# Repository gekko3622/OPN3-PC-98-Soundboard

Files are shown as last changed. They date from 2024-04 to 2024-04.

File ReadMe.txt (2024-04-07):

  ___  ____  _   _ _____  __     ______    ___  
 / _ \|  _ \| \ | |___ /  \ \   / /___ \  / _ \ 
| | | | |_) |  \| | |_ \   \ \ / /  __) || | | |
| |_| |  __/| |\  |___) |   \ V /  / __/ | |_| |
 \___/|_|   |_| \_|____/     \_/  |_____(_)___/ 

PC-9801/9821 Soundboard
2024.3 by RLB (Gekko3622)
Original schematic by Ethy1ene

Intro:

This ZIP archive contains all files related to my implementation of Ethy1ene's publicly released OPN3 schematic. Please feel free to modify or improve it in any way you see fit.

------------------------------------------------------------------------------------------------------

ZIP Contents:

1. KiCAD Project - Contains the full KiCad project for my version of the OPN3 soundboard.

2. Production Files - Contains all files necessary to produce the exact PCB that I have. 
   
   I HIGHLY RECOMMEND paying your PCB fabricator to supply and assemble the small SMD devices. 
   This folder includes turnkey BOM and top placement files formatted for JLCPCB.
   
   This will include my logo on the PCB, as it is guaranteed to be an exact match to my own design.
   If you wish to produce a PCB without my logo, you will need to export new fabrication files from KiCad.

3. JEDEC File - Contains a .JED file that must be programmed to the GAL20V8.
                This is mandatory. Please ensure you have a programmer that can write to a GAL20V8.

4. DigiKey Order List - Lists all components I purchased from DigiKey. Anything not on this list was 
   purchased for assembly by JLCPCB or needed to be purchased used or new old stock (see below).

------------------------------------------------------------------------------------------------------

Used/New Old Stock Parts Required:

1. YMF288-M Sound Chip
2. NEC UPD6379GR 16-Bit DAC
3. Lattice GAL20V8B-25LP Programmable Logic Device (PLD)

Note 1: UPD6379A is a pin-reversed variant. If you use it for some reason, it needs to be rotated 180 degrees.
Note 2: National Semiconductor makes a GAL20V8 which is still available. I have not tested it and cannot tell you which part number would be the best match.

------------------------------------------------------------------------------------------------------

Credits:

HUGE thanks to Ethy1ene for releasing his original OPN3 soundboard schematic and providing advice and troubleshooting. Without his help, this project wouldn't exist.

Thanks also to TD-Linux and i509VCB for their advice and guidance, pushing me to learn better practices as I worked.

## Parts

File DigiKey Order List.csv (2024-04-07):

Index | DigiKey Part # | Manufacturer Part Number | Description | Customer Reference | Quantity | Backorder | Unit Price | Extended Price
1 | FK0800019QDICT-ND | FK0800019Q | XTAL OSC XO 8.0000MHZ CMOS SMD | X1 | 1 | 0 | $1.31 | $1.31
2 | 296-3677-1-ND | SN74LS245NSR | IC TXRX NON-INVERT 5.25V 20SO | U4 | 1 | 0 | $1.20 | $1.20
3 | AZ1117IH-5.0TRG1DICT-ND | AZ1117IH-5.0TRG1 | IC REG LINEAR 5V 1A SOT223 | U8 | 1 | 0 | $0.38 | $0.38
4 | LM386MX-1/NOPBCT-ND | LM386MX-1/NOPB | IC AMP CLASS AB MONO 325MW 8SOIC | U7 | 1 | 0 | $1.11 | $1.11
5 | 296-LM2904DRCT-ND | LM2904DR | IC OPAMP GP 2 CIRCUIT 8SOIC | U6 | 1 | 0 | $0.41 | $0.41
6 | 1727-2787-1-ND | 74HC164D,653 | IC SHIFT REGST 8BIT SI-PO 14SOIC | U5 | 1 | 0 | $0.46 | $0.46
7 | CP1-3535NS-ND | SJ1-3535NS | CONN JACK STEREO 3.5MM R/A |  | 1 | 0 | $1.49 | $1.49
8 | 4809-RK09K1110A0J-ND | RK09K1110A0J | POT 10K OHM 1/20W LINEAR | RV1 | 1 | 0 | $1.80 | $1.80
 |  |  |  |  |  |  | Subtotal | $8.16

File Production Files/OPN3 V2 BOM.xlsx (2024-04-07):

Comment | Designator | Footprint | Quantity | JLCPCB Part #（optional）
10UF | C1 | Capacitor_Tantalum_SMD:CP_EIA-3216-18_Kemet-A | 1 | Basic C7171
10UF | C2, C4, C8 | Capacitor_SMD:C_0603_1608Metric | 3 | Basic C96446
0.1UF | C3, C16, C17, C18, C19, C20, C21, C22, C23 | Capacitor_SMD:C_0603_1608Metric | 9 | Basic C14663
2.2UF | C5, C9 | Capacitor_SMD:C_0603_1608Metric | 2 | Basic C23630
200PF | C6, C10 | Capacitor_SMD:C_0603_1608Metric | 2 | Extended C113796
10UH | L1, L2 | Inductor_SMD:L_1206_3216Metric | 2 | Extended C1051
1K | R1, R2, R3 | Resistor_SMD:R_0603_1608Metric | 3 | Basic C21190
10K | R4, R9, R11, R12, R17, R18, R19, R20, R21 | Resistor_SMD:R_0603_1608Metric | 9 | Basic C25804
470 | R5 | Resistor_SMD:R_0603_1608Metric | 1 | Basic C23179
680 | R6 | Resistor_SMD:R_0603_1608Metric | 1 | Basic C23228
3.3K | R7, R13 | Resistor_SMD:R_0603_1608Metric | 2 | Basic C22978
10 | R8, R14 | Resistor_SMD:R_0603_1608Metric | 2 | Basic C22859
5.6K | R10, R15 | Resistor_SMD:R_0603_1608Metric | 2 | Basic C23189
1.2K | R16 | Resistor_SMD:R_0603_1608Metric | 1 | Basic C22765

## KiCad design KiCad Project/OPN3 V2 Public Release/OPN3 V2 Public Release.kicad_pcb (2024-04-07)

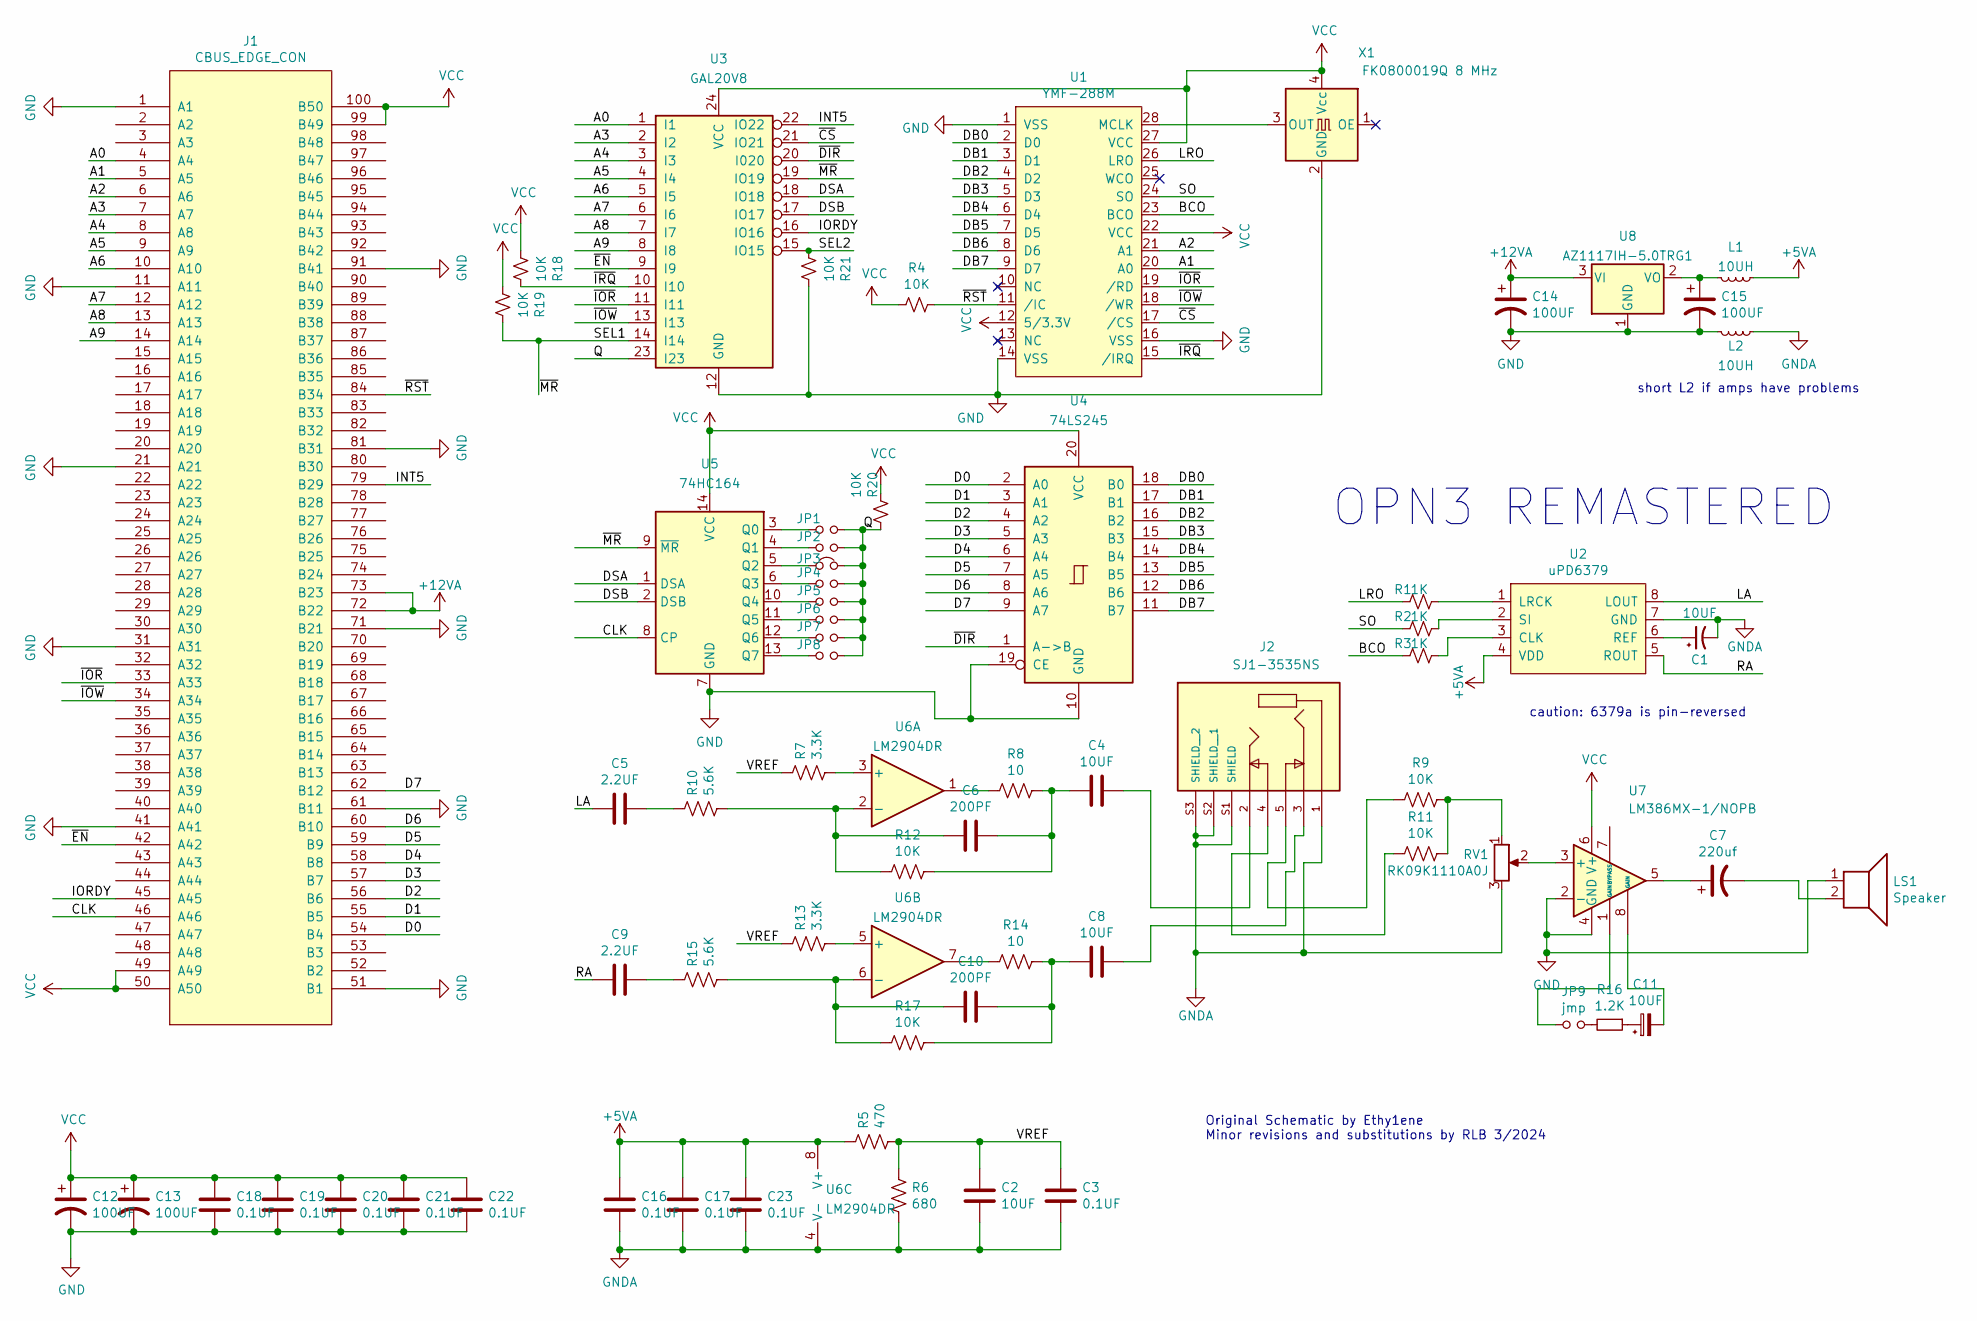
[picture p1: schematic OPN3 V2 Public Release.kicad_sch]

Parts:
C1: 10UF; CP_EIA-3216-18_Kemet-A
C2, C4, C8: 10UF; C_0603_1608Metric
C3, C16, C17, C18, C19, C20, C21, C22, C23: 0.1UF; C_0603_1608Metric
C5, C9: 2.2UF; C_0603_1608Metric
C6, C10: 200PF; C_0603_1608Metric
C7: 220uf; CP_Radial_D5.0mm_P2.50mm
C11: 10UF; CP_Radial_D6.3mm_P2.50mm
C12, C13, C14, C15: 100UF; CP_Radial_D6.3mm_P2.50mm
J1: CBUS_EDGE_CON; PC-98 CBus Pads 1-100
J2: SJ1-3535NS; CUI_SJ1-3535NS
JP1, JP2, JP4, JP5, JP6, JP7, JP8: Jumper_NO_Small; SolderJumper-2_P1.3mm_Open_Pad1.0x1.5mm
JP3: W; SolderJumper-2_P1.3mm_Bridged_Pad1.0x1.5mm
JP9: jmp; SolderJumper-2_P1.3mm_Open_Pad1.0x1.5mm
L1, L2: 10UH; L_1206_3216Metric
LS1: Speaker; PinHeader_1x02_P2.54mm_Vertical
R1, R2, R3: 1K; R_0603_1608Metric
R4, R9, R11, R12, R17, R18, R19, R20, R21: 10K; R_0603_1608Metric
R5: 470; R_0603_1608Metric
R6: 680; R_0603_1608Metric
R7, R13: 3.3K; R_0603_1608Metric
R8, R14: 10; R_0603_1608Metric
R10, R15: 5.6K; R_0603_1608Metric
R16: 1.2K; R_0603_1608Metric
RV1: RK09K1110A0J; Potentiometer_Alps_RK09K_Single_Horizontal; Part# ALPS RK09K1110B1R
U1: YMF-288M; YMF288-M; DigiKey Link None, source used/new old stock
U2: uPD6379; SOIC-8_5.23x5.23mm_P1.27mm; DigiKey Link None, source used/new old stock
U3: GAL20V8; DIP-24_W7.62mm
U4: 74LS245; SO-20_5.3x12.6mm_P1.27mm
U5: 74HC164; SO-14_5.3x10.2mm_P1.27mm
U6: LM2904DR; SOIC-8_5.23x5.23mm_P1.27mm
U7: LM386MX-1/NOPB; SOIC-8_5.23x5.23mm_P1.27mm
U8: AZ1117IH-5.0TRG1; SOT-223-3_TabPin2
X1: FK0800019Q 8 MHz; Oscillator_SMD_SeikoEpson_SG8002CE-4Pin_3.2x2.5mm_HandSolde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

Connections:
+5VA: C16.1, C17.1, C23.1, L1.2, R5.1, U2.4 (VDD), U6.8 (V+)
+12VA: C14.1, J1.72 (B22), J1.73 (B23), U8.3 (VI)
/A0: J1.4 (A4), U3.1 (I1)
/A1: J1.5 (A5), U1.20 (A0)
/A2: J1.6 (A6), U1.21 (A1)
/A3: J1.7 (A7), U3.2 (I2)
/A4: J1.8 (A8), U3.3 (I3)
/A5: J1.9 (A9), U3.4 (I4)
/A6: J1.10 (A10), U3.5 (I5)
/A7: J1.12 (A12), U3.6 (I6)
/A8: J1.13 (A13), U3.7 (I7)
/A9: J1.14 (A14), U3.8 (I8)
/BCO: R3.1, U1.23 (BCO)
/CLK: J1.46 (A46), U5.8 (CP)
/D0: J1.54 (B4), U4.2 (A0)
/D1: J1.55 (B5), U4.3 (A1)
/D2: J1.56 (B6), U4.4 (A2)
/D3: J1.57 (B7), U4.5 (A3)
/D4: J1.58 (B8), U4.6 (A4)
/D5: J1.59 (B9), U4.7 (A5)
/D6: J1.60 (B10), U4.8 (A6)
/D7: J1.62 (B12), U4.9 (A7)
/DB0: U1.2 (D0), U4.18 (B0)
/DB1: U1.3 (D1), U4.17 (B1)
/DB2: U1.4 (D2), U4.16 (B2)
/DB3: U1.5 (D3), U4.15 (B3)
/DB4: U1.6 (D4), U4.14 (B4)
/DB5: U1.7 (D5), U4.13 (B5)
/DB6: U1.8 (D6), U4.12 (B6)
/DB7: U1.9 (D7), U4.11 (B7)
/DSA: U3.18 (IO18), U5.1 (DSA)
/DSB: U3.17 (IO17), U5.2 (DSB)
/INT5: J1.79 (B29), U3.22 (IO22)
/IORDY: J1.45 (A45), U3.16 (IO16)
/LA: C5.1, U2.8 (LOUT)
/LRO: R1.1, U1.26 (LRO)
/Q: JP1.2, JP2.2, JP3.2, JP4.2, JP5.2, JP6.2, JP7.2, JP8.2, R20.1, U3.23 (I23)
/RA: C9.1, U2.5 (ROUT)
/SEL1: R19.1, U3.14 (I14), U3.19 (IO19), U5.9 (~MR)
/SEL2: R21.2, U3.15 (IO15)
/SO: R2.1, U1.24 (SO)
/VREF: C2.1, C3.1, R5.2, R6.1, R7.1, R13.1
/~CS: U1.17 (/CS), U3.21 (IO21)
/~DIR: U3.20 (I020), U4.1 (A->B)
/~EN: J1.42 (A42), U3.9 (I9)
/~IOR: J1.33 (A33), U1.19 (/RD), U3.11 (I11)
/~IOW: J1.34 (A34), U1.18 (/WR), U3.13 (I13)
/~IRQ: R18.1, U1.15 (/IRQ), U3.10 (I10)
/~RST: J1.84 (B34), R4.1, U1.11 (/IC)
GND: C12.2, C13.2, C14.2, C15.2, C18.2, C19.2, C20.2, C21.2, C22.2, J1.1 (A1), J1.11 (A11), J1.21 (A21), J1.31 (A31), J1.41 (A41), J1.51 (B1), J1.61 (B11), J1.71 (B21), J1.81 (B31), J1.91 (B41), L2.1, LS1.1, R21.1, U1.1 (VSS), U1.14 (VSS), U1.16 (VSS), U3.12 (GND), U4.10 (GND), U4.19 (CE), U5.7 (GND), U7.2 (-), U7.4 (GND), U8.1 (GND), X1.2 (GND)
GNDA: C1.2, C2.2, C3.2, C16.2, C17.2, C23.2, J2.1, J2.S1 (SHIELD), J2.S2 (SHIELD__1), J2.S3 (SHIELD__2), L2.2, R6.2, RV1.3, U2.7 (GND), U6.4 (V-)
unnamed: C4.1, J2.2
unnamed: C4.2, C6.1, R8.1, R12.1
unnamed: C5.2, R10.1
unnamed: C7.1, U7.5
unnamed: C7.2, LS1.2
unnamed: C8.1, J2.3
unnamed: C9.2, R15.1
unnamed: C8.2, C10.1, R14.1, R17.1
unnamed: C11.1, R16.1
unnamed: C11.2, U7.8 (GAIN)
unnamed: J2.4, R11.2
unnamed: J2.5, R9.2
unnamed: JP9.1, U7.1 (GAIN)
unnamed: JP9.2, R16.2
unnamed: R8.2, U6.1
unnamed: R9.1, R11.1, RV1.1
unnamed: R14.2, U6.7
unnamed: U1.28 (MCLK), X1.3 (OUT)
unnamed: R3.2, U2.3 (CLK)
unnamed: R1.2, U2.1 (LRCK)
unnamed: C1.1, U2.6 (REF)
unnamed: R2.2, U2.2 (SI)
unnamed: JP1.1, U5.3 (Q0)
unnamed: JP2.1, U5.4 (Q1)
unnamed: JP3.1, U5.5 (Q2)
unnamed: JP4.1, U5.6 (Q3)
unnamed: JP5.1, U5.10 (Q4)
unnamed: JP6.1, U5.11 (Q5)
unnamed: JP7.1, U5.12 (Q6)
unnamed: JP8.1, U5.13 (Q7)
unnamed: R7.2, U6.3 (+)
unnamed: C6.2, R10.2, R12.2, U6.2 (-)
unnamed: R13.2, U6.5 (+)
unnamed: C10.2, R15.2, R17.2, U6.6 (-)
unnamed: RV1.2, U7.3 (+)
unnamed: C15.1, L1.1, U8.2 (VO)
VCC: C12.1, C13.1, C18.1, C19.1, C20.1, C21.1, C22.1, J1.49 (A49), J1.50 (A50), J1.99 (B49), J1.100 (B50), R4.2, R18.2, R19.2, R20.2, U1.12 (5/3.3V), U1.22 (VCC), U1.27 (VCC), U3.24 (VCC), U4.20 (VCC), U5.14 (VCC), U7.6 (V+), X1.4 (Vcc)

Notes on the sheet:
Original Schematic by Ethy1ene Minor revisions and substitutions by RLB 3/2024
OPN3 REMASTERED
caution: 6379a is pin-reversed
short L2 if amps have problems

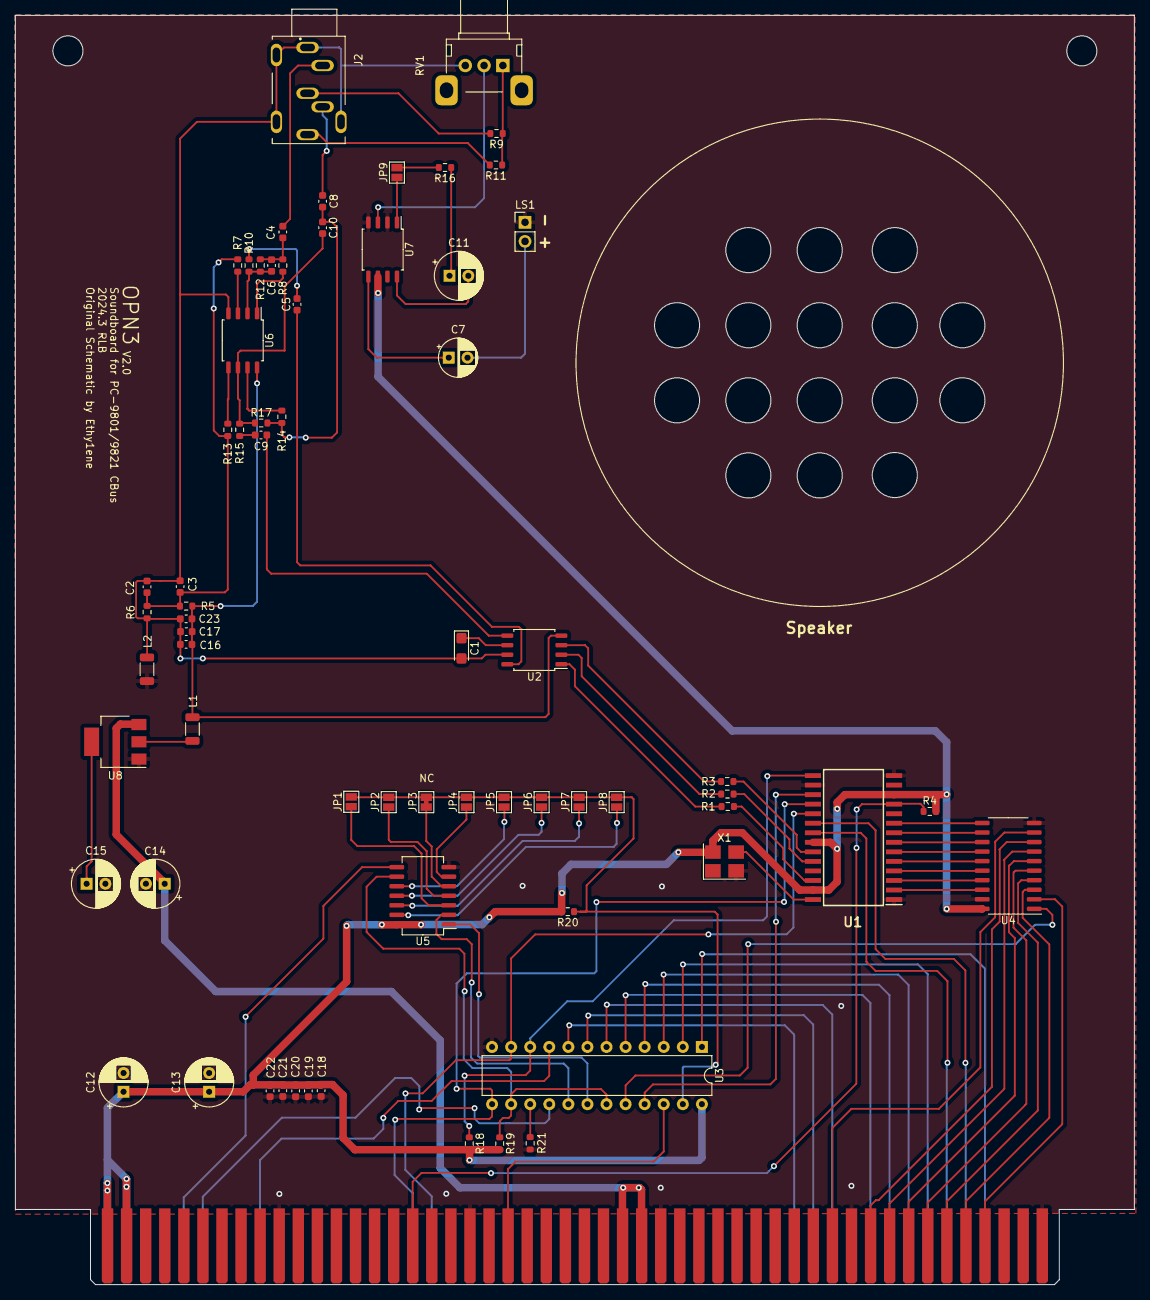
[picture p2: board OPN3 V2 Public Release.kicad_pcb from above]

Board: 2 copper layers, 149.0 x 169.0 mm, 68 parts (0 on the bottom side), 88 nets.
